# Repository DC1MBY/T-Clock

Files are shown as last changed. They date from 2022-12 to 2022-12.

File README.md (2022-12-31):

# T-Clock: A Nixie tube clock build from transistors only

The first working transistor demo just had its 75th anniversary: https://en.wikipedia.org/wiki/History_of_the_transistor How to better celebrate it than having (103 times) fun with transistors? Some time back I discovered in the German magazine Funkschau 1969 #2, #3 and #10 the article "Digital-Uhr zum Selbstbau", a copy of it can be found here: http://www.nixieuhren.de/downloads/digitaluhrfunkschau.pdf 
It is a Nixie clock design completely based on transistors. I always wanted to build one of these. When I found out that Kicad supports auto routing (freeRouting/LayoutEditor), that became much more feasible. This repository contains the PCB designs as well as OpenScad designs for the case and the spacer for the Nixies.

**Warning: Nixie tubes require high voltages which can be lethal. Please be careful!**

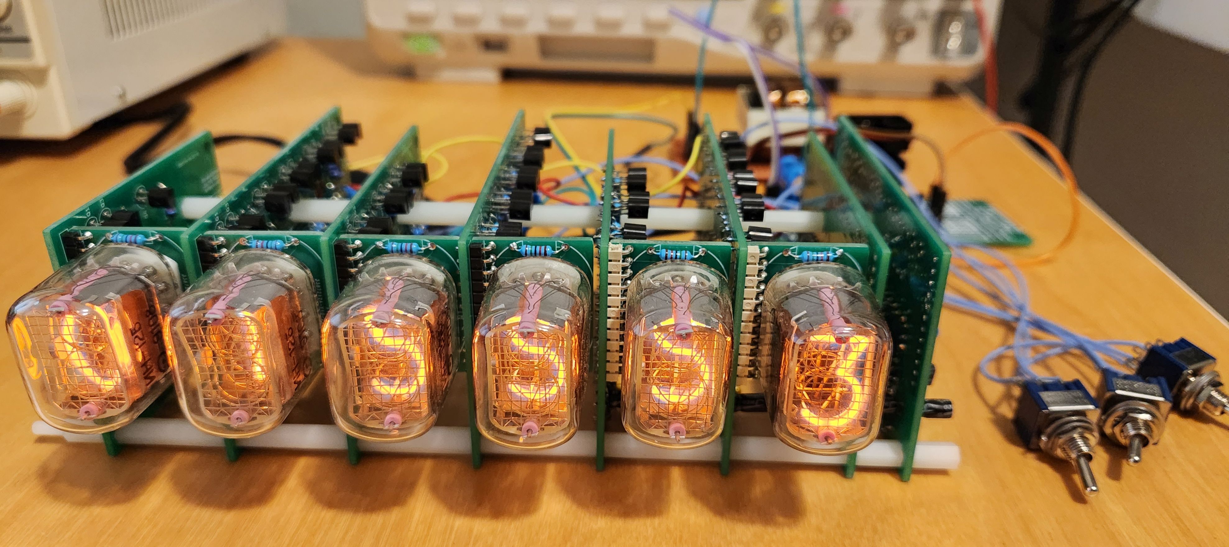
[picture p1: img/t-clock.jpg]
t-clock


## Changes compared to the original

### Prescaler

I'm living in US, so I had to modify the prescaler from 50Hz to 60Hz mains frequency. /60 can be very easy implemented as /10 followed by /6. This allowed to re-use the PCBs of the first and second digit, just the decoding/high voltage transistors aren't populated on these PCBs. Luckily the usual PCB prototype manufactures always send a couple of copies of each ordered PCB, very handy for that.

### Schmitt-Trigger

The Schmitt trigger for converting the sinusoidal mains signal to a square wave feeding the prescaler was converted from Ge to Si. Because the circuit is small, I didn't develop a pcb for it but implemented it on a piece of perfboard. 

### Power Supply

Power source is a 12VAC 1.5A wall wart, this way no routing of mains voltage is needed. The high voltage for the Nixie tubes is generated by a small reverse operated transformer. Because of the high DC resistance of the transformer the supply is very soft and reaching the correct voltage (about 170V) is a bit critical. Therefore the rectified 12V was added in order to reach the required voltage. If this is needed or not will depend on the type of transformer. The Ge transistors of the 12V regulator were replaced by Si ones. The pass transistor needs a heatsink. A perfboard was used for the power supply. 

## Obtaining the parts

All components are easily obtainable except for the Nixie tubes. The IN-12 Nixie tube can still be found on ebay. Because the decimal point isn't used, both the IN-12A and IN-12B version will work fine.

## Block Diagram

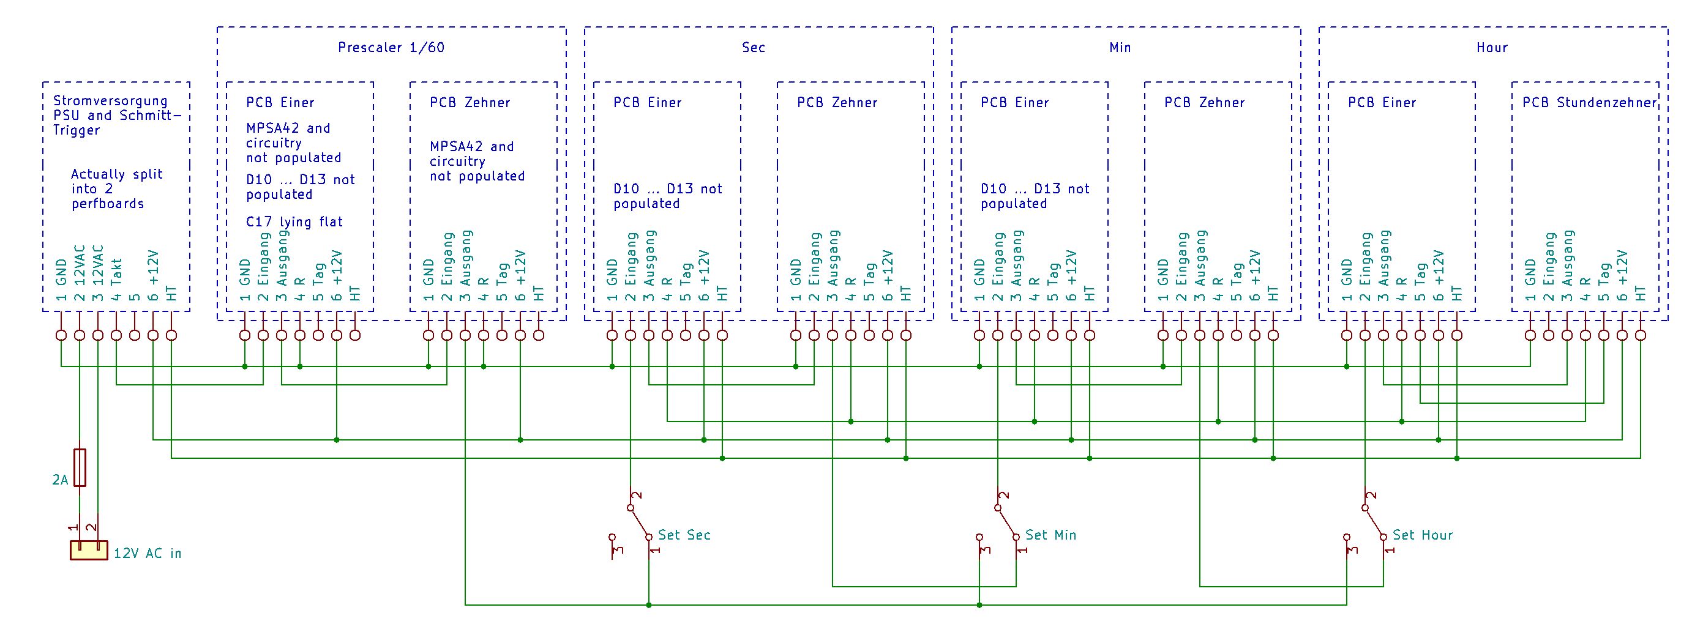
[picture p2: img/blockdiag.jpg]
Block Diagram


## Mechanical

### Boards

The boards are stacked with 25mm M3 spacers and 10mm M3 spacers. The stack will be mounted to the case.
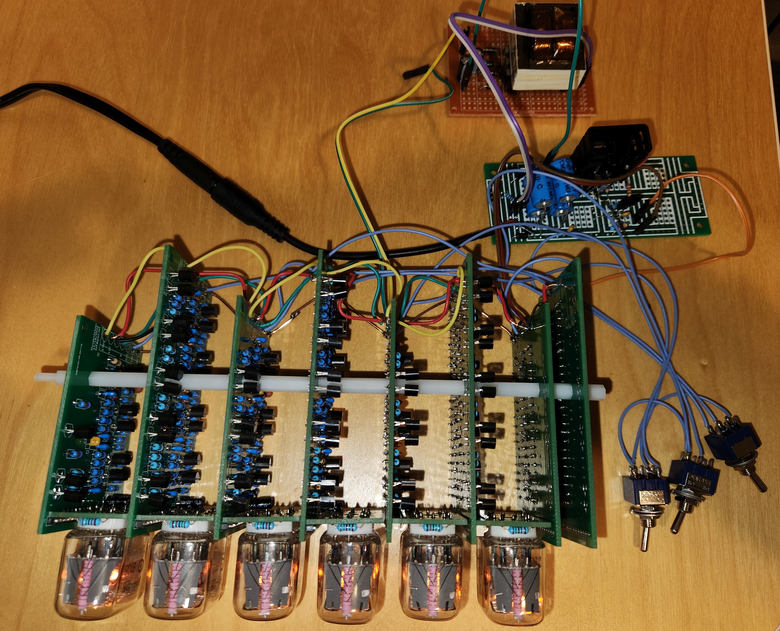
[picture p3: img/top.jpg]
boards


### Nixie

Even more difficult to source than the Nixie tubes themselves are sockets for them. Therefore I soldered the Nixie tubes directly to the PCB. I've seen this method first in Russian test equipment offered on a flea market. For equally spacing the Nixie from the PCB a 3d printed spacer is used (in12b.scad).  
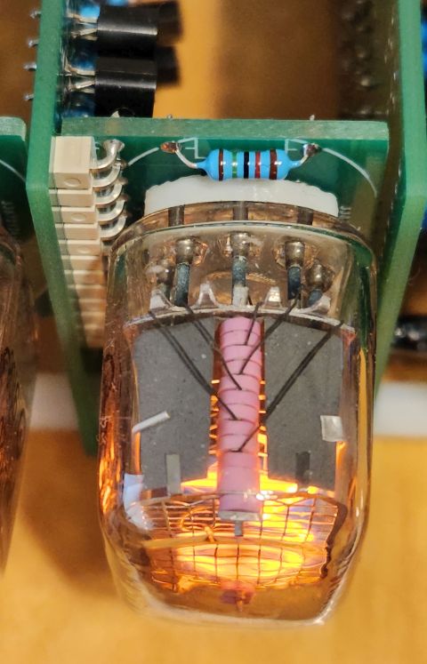
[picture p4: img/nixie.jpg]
nixie


### Case

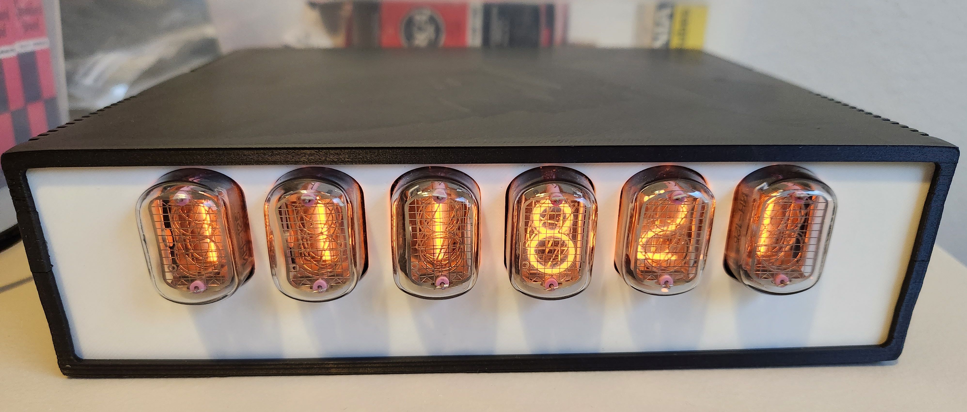
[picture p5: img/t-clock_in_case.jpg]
t-clock in case


The case is based on the fantastic Ultimate Box Maker https://github.com/jbebel/Ultimate-Box-Maker. The pcb mounts and the tabs are using M2.5 metal threaded inserts https://www.amazon.com/gp/product/B07NBPGTY2 .

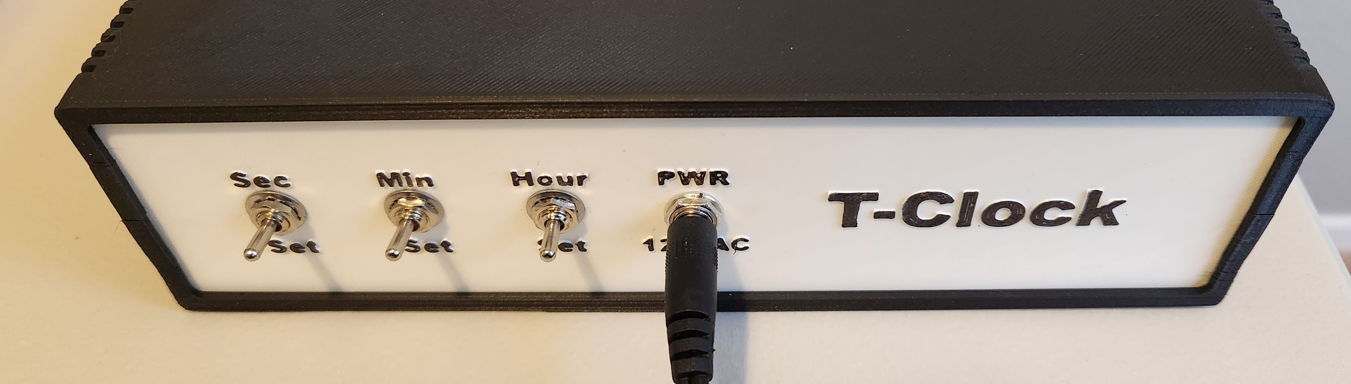
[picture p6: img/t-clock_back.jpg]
t-clock back


The letters in the back panel are painted black with a sharpie. 

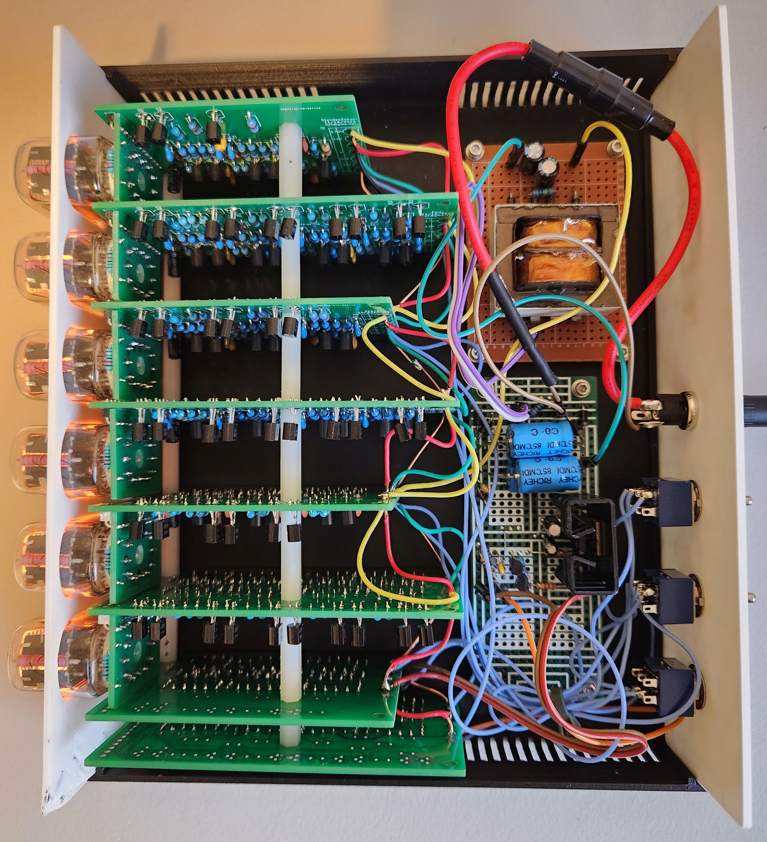
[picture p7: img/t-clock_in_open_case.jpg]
t-clock in open case


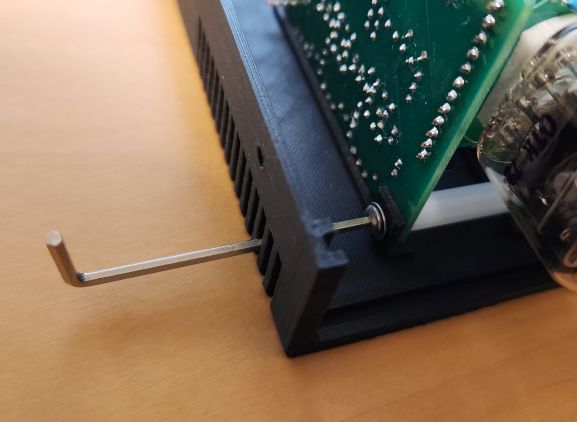
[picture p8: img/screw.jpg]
screw mounting the stack to the case


The screws can be installed with an Allen key through the vent. For the picture I didn't have the front panel installed yet, but the front panel needs to be installed before the screws. In this version of the case the tab was 2 mm thick and I broke one off. Therefore I made it 4mm thick. It might be best to print it with 100% infill for added stability.

## Summary

Things I might change if I'd redesign it:
- Move the Nixies to the center of the pcb for better looks
- Add a second mounting hole to the pcbs on the lower side (I made the usual mistake to first layout the pcbs and then think about the case)
- Change to SMD components. I forgot how tedious it is to bend the leads and clip them.   

That was a fun project. It turned out to be quite easy to build a more than 50 years old design today. I fear one of today's "modern" Nixie clock designs based on an microcontroller will be much harder to build in 50 years from now, the toolchain for the controller will not work with Windows 2070, USB20 will be incompatible with USB2.0, ... ;)

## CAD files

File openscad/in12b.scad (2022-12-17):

//
//
// IN12 spacer
//
//

pinradius = 1.8 / 2;

difference(){
    cylinder(h = 3.5,r = 22/2, center = true, $fn=360);
    
    union(){
    translate([0,0,-5])
    cylinder(h = 100,r = 3.5, $fn=360);

    translate([0,-9,-5])
    cylinder(h = 100,r = pinradius, $fn=360);
    
    translate([0,9,-5])
    cylinder(h = 100,r = pinradius, $fn=360);
    
    translate([4,-8,-5])
    cylinder(h = 100,r = pinradius, $fn=360);
    
    translate([4,8,-5])
    cylinder(h = 100,r = pinradius, $fn=360);
    
    translate([-4,-8,-5])
    cylinder(h = 100,r = pinradius, $fn=360);
    
    translate([-4,8,-5])
    cylinder(h = 100,r = pinradius, $fn=360);
    
    translate([11.5/2,4.5,-5])
    cylinder(h = 100,r = pinradius, $fn=360);
    
    translate([11.5/2,-4.5,-5])
    cylinder(h = 100,r = pinradius, $fn=360);

    translate([-11.5/2,4.5,-5])
    cylinder(h = 100,r = pinradius, $fn=360);
    
    translate([-11.5/2,-4.5,-5])
    cylinder(h = 100,r = pinradius, $fn=360);

    translate([11.5/2,0,-5])
    cylinder(h = 100,r = pinradius, $fn=360);
    
    translate([11.5/2,0,-5])
    cylinder(h = 100,r = pinradius, $fn=360);

    translate([-11.5/2,0,-5])
    cylinder(h = 100,r = pinradius, $fn=360);
    
    translate([-11.5/2,0,-5])
    cylinder(h = 100,r = pinradius, $fn=360);

    translate([7.5,-11,-5])
    cube([22,22,20]);

    translate([-22-7.5,-11,-5])
    cube([22,22,20]);


    }
}

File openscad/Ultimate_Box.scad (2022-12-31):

/* Box design originally by:
////////////////////////////////////////////////////////////////////
              -    FB Aka Heartman/Hearty 2016     -
              -   http://heartygfx.blogspot.com    -
              -       OpenScad Parametric Box      -
              -         CC BY-NC 3.0 License       -
////////////////////////////////////////////////////////////////////

Improved by jbebel:
http://github.com/jbebel/Ultimate-Box-Maker

To create a box, start by modifying the numerical parameters in the sections
below. This can be accomplished using a release of OpenSCAD newer than 2015.03.
As of the time of writing, this means that a development snapshot is required.
The Thingiverse Customizer may also potentially work, but at the time of
writing, it was inoperable.

The simplest choice is to hand-edit the .scad file. Feature toggles are
annotated with a comment. The other numerical parameters are measurements in
mm. Everything is parametrized, so if you double all the non-feature parameters
you will double the box size in every dimension. Certain parameters are derived
from other parameters. If you wish to override them, you may, but sensible
defaults have been chosen. Notably the design in this revision is particularly
PCB-centric, in that you should start with your PCB size and adjust the margins
around it to determine the box size. If you care more about the box size, you
can set the Length, Width, and Height explicitly, but read the comments around
them.

Once your box is sized appropriately, you can use the Panel modules to design
the holes and text for the front and back panels. Helper variables are provided
to assist you in positioning these holes relative to the PCB, if your holes are
for PCB-mounted components.

When you are ready to print, adjust the values in the "STL element to export"
section, and export each part one at a time.

Experimental options are provided for a screwless design, but these are
untested. In particular, the box fixation tabs may need thicknesses adjusted
in order to have the appropriate flexibility.
*/

// preview[view:north east, tilt:top diagonal]
//----------------------- Box parameters ---------------------------

/* [Box options] */
// - Wall thickness
Thick = 2;
// - Panel thickness
PanelThick = 2;
// - Font Thickness
FontThick = 0.5;
// - Filet Radius
Filet = 2;
// - 0 for beveled, 1 for rounded
Round = 1; // [0:No, 1:Yes]
// - Printer margin around interior cutouts
CutoutMargin = 0.3;
// - Margin between mating parts
PartMargin = 0.1;
// - PCB feet? (x4)
PCBFeet = 1; // [0:No, 1:Yes]
// - Decorations?
Decorations = 1; // [0:No, 1:Yes]
// - Decorations to ventilation holes
Vent = 1; // [0:No, 1:Yes]
// - Decoration-Holes width (in mm)
Vent_width = 2;
// - Tolerance (Panel/rails gap on one edge)
PanelThickGap = CutoutMargin + PartMargin;
PanelVerticalGap = PartMargin;
PanelHorizontalGap = CutoutMargin + PartMargin;


/* [Box Fixation Tabs] */
// - Side screw hole (or snap) diameter
ScrewHole = 3.7;  // M2.5 metal threaded insert
// - Screw thread major diameter for outer shell
BoxHole = 2.8448;
// Thickness of fixation tabs
TabThick = 5.5;
// Back left tab
BLTab = 1; // [0:Bottom, 1:Top]
// Back right tab
BRTab = 1; // [0:Bottom, 1:Top]
// Front left tab
FLTab = 1; // [0:Bottom, 1:Top]
// Front right tab
FRTab = 1; // [0:Bottom, 1:Top]
// EXPERIMENTAL: Snap tabs
SnapTabs = 0; // [0:Screws, 1:Snaps]


/* [PCB options] */
// - PCB Length
PCBLength = 40;
PCBLength_2 = 50;
// - PCB Width
PCBWidth = 100;
PCBWidth_2 = 70;
// Offset of the 2nd pcb to the 1st
PCB2XOff = -10;
PCB2YOff = -75;
// - PCB Thickness
PCBThick = 1.6;
// You likely need to maintain |TabThick| margin on the left and right for tabs
// and whatnot.
// - Margin between front panel and PCB
FrontEdgeMargin = 110;
// - Margin between back panel and PCB
BackEdgeMargin = 20;
// - Margin between left wall and PCB
LeftEdgeMargin = 84.8+8;
// - Margin between right wall and PCB
RightEdgeMargin = 8+8;
// - Margin between top of PCB and box top.
TopMargin = 53.34-1.6-6;


/* [PCB_Feet] */
// - Foot height above box interior
FootHeight = 6;
// - Foot diameter
FootDia = 8;
// - Hole diameter, or peg for screwless design
FootHole = 3.7; // M2.5 metal threaded insert
// - EXPERIMENTAL Screwless design
Screwless = 0; // [0:Screws, 1:Screwless]
FootFilet = FootHeight/4;

// Foot centers are specified as distance from PCB back-left corner.
// X is along the "length" axis, and Y is along the "width" axis.
// - Foot 1 distance from back PCB edge
Foot1X = 5;
// - Foot 1 distance from left PCB edge
Foot1Y = 4;
// - Foot 2 distance from back PCB edge
Foot2X = 5;
// - Foot 2 distance from right PCB edge
Foot2YFromEdge = 4;
Foot2Y = PCBWidth - Foot2YFromEdge;
// - Foot 3 distance from front PCB edge
Foot3XFromEdge = 5;
Foot3X = PCBLength - Foot3XFromEdge;
// - Foot 3 distance from left PCB edge
Foot3Y = 4;
// - Foot 4 distance from front PCB edge
Foot4XFromEdge = 5;
Foot4X = PCBLength - Foot4XFromEdge;
// - Foot 4 distance from right PCB edge
Foot4YFromEdge = 4;
Foot4Y = PCBWidth - Foot4YFromEdge;

// 2nd PCB
// Foot centers are specified as distance from PCB back-left corner.
// X is along the "length" axis, and Y is along the "width" axis.
// - Foot 1 distance from back PCB edge
Foot1X_2 = 2.5;
// - Foot 1 distance from left PCB edge
Foot1Y_2 = 2.5;
// - Foot 2 distance from back PCB edge
Foot2X_2 = 2.5;
// - Foot 2 distance from right PCB edge
Foot2YFromEdge_2 = 2.5;
Foot2Y_2 = PCBWidth_2 - Foot2YFromEdge_2;
// - Foot 3 distance from front PCB edge
Foot3XFromEdge_2 = 2.5;
Foot3X_2 = PCBLength_2 - Foot3XFromEdge_2;
// - Foot 3 distance from left PCB edge
Foot3Y_2 = 2.5;
// - Foot 4 distance from front PCB edge
Foot4XFromEdge_2 = 2.5;
Foot4X_2 = PCBLength_2 - Foot4XFromEdge_2;
// - Foot 4 distance from right PCB edge
Foot4YFromEdge_2 = 2.5;
Foot4Y_2 = PCBWidth_2 - Foot4YFromEdge_2;


/* [STL element to export] */
// - Top shell
TShell = 0; // [0:No, 1:Yes]
// - Bottom shell
BShell = 1; // [0:No, 1:Yes]
// - Front panel
FPanL = 0; // [0:No, 1:Yes]
// - Back panel
BPanL = 0; // [0:No, 1:Yes]
// - Panel holes and text
PanelFeatures = 1; // [0:No, 1:Yes]


/* [Hidden] */
// - Shell color
Couleur1 = "Orange";
// - Panel color
Couleur2 = "OrangeRed";
// - Text color
TextColor = "White";
// - making decorations thicker if it is a vent to make sure they go through
// shell
// Add a small number to Thick in case Filet is 0.
Dec_Thick = Vent ? Thick*1.001 + Filet : Thick/2;
// Separate vents with a square pillar by default.
Dec_Spacing = Thick + Vent_width;
// X offset to center of first vent
Dec_Offset = Thick*2 + PanelThick + PanelThickGap*2 + Dec_Spacing - Vent_width/2;

// Resolution based on Round parameter. Set this first number to something
// smaller to speed up processing. It should always be a multiple of 4.
Resolution = Round ? 100: 4;

/* Calculate box dimensions from PCB. If you want a more box-centric design
   where the outer diameter of the box matters more than the margins around
   the PCB you can set these manually. The PCB will still be placedaccording
   to the left and back margins, and if you want to use the screwless box
   design, you will need to set the TopMargin to
   (Height - Thick*2 - FootHeight - PCBThick)
*/
Length = PCBLength + FrontEdgeMargin + BackEdgeMargin + ((Thick + PanelThick + PanelThickGap*2)*2);
Width = PCBWidth + LeftEdgeMargin + RightEdgeMargin + Thick*2;
Height = FootHeight + PCBThick + TopMargin + Thick*2;
echo("Box: ", Length=Length, Width=Width, Height=Height);
// X position inset of mounting holes and tabs
MountInset = Thick*3 + PanelThick + PanelThickGap*2 + ScrewHole*4;

// Calculate panel dimensions from box dimensions.
PanelWidth = Width - Thick*2 - PanelHorizontalGap*2;
PanelHeight = Height - Thick*2 - PanelVerticalGap*2;


/*  Panel Manager

    Use the below 4 modules to produce holes and text on the front and back
    panels. The holes modules should contain instances of SquareHole or
    CylinderHole defined later in this file. The text modules should contain
    instances of LText or CText defined later in this file. It is
    recommended to use variables that you define for your needs to create
    the size and positions of these objects.
*/

// Calculate board-relative positions with respect to the panel, for
// convenience in placing panel elements.
TopOfBoardWRTPanel = FootHeight + PCBThick - PanelVerticalGap;
LeftEdgeOfBoardWRTFPanel = LeftEdgeMargin - PanelHorizontalGap;
LeftEdgeOfBoardWRTBPanel = RightEdgeMargin - PanelHorizontalGap;
// Visible panel edges
PanelBottomEdge = Thick - PanelVerticalGap;
PanelTopEdge = PanelHeight - Thick + PanelVerticalGap;
PanelLeftEdge = Thick - PanelHorizontalGap;
PanelRightEdge = PanelWidth - Thick + PanelHorizontalGap;


// Holes for front panel
module FPanelHoles() {
    // SquareHole(On/Off, Xpos,Ypos,Length,Width,Filet)
    // CylinderHole(On/Off, Xpos, Ypos, Diameter)
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

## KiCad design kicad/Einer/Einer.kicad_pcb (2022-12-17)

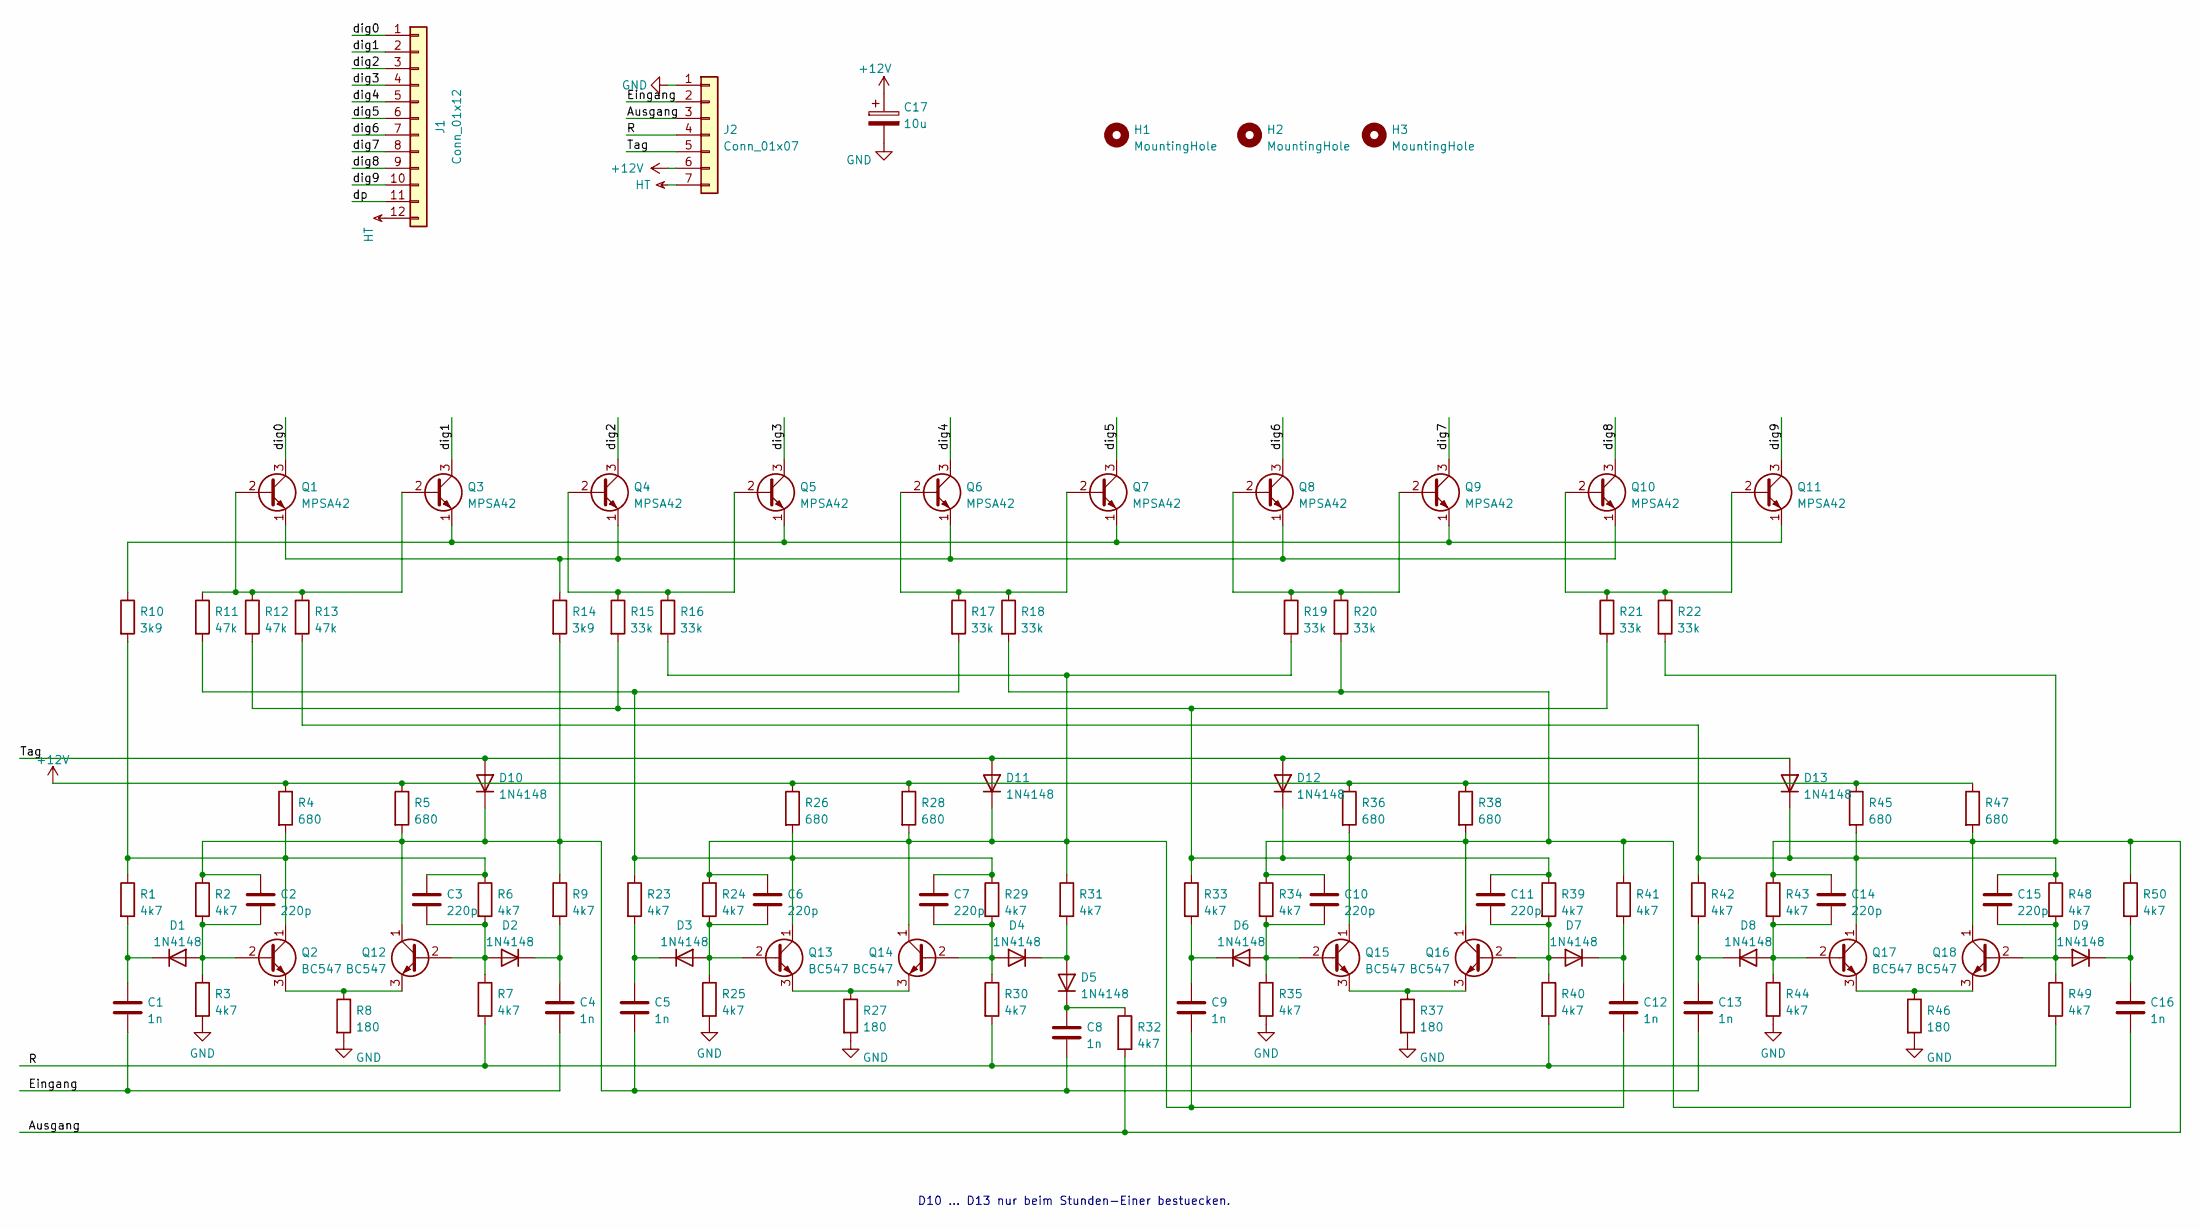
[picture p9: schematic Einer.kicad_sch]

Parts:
C1, C4, C5, C8, C9, C12, C13, C16: 1n; C_Disc_D5.0mm_W2.5mm_P2.50mm
C2, C3, C6, C7, C10, C11, C14, C15: 220p; C_Disc_D5.0mm_W2.5mm_P2.50mm
C17: 10u; CP_Radial_D5.0mm_P2.50mm
D1, D2, D3, D4, D5, D6, D7, D8, D9, D10, D11, D12, D13: 1N4148; D_DO-35_SOD27_P7.62mm_Horizontal
H1, H2, H3: MountingHole; MountingHole_3.2mm_M3
J1: Conn_01x12; PinHeader_1x12_P2.54mm_Vertical
J2: Conn_01x07; TerminalBlock_Phoenix_MKDS-3-7-5.08_1x07_P5.08mm_Horizontal
Q1, Q3, Q4, Q5, Q6, Q7, Q8, Q9, Q10, Q11: MPSA42; TO-92_HandSolder
Q2, Q12, Q13, Q14, Q15, Q16, Q17, Q18: BC547; TO-92_HandSolder
R1, R2, R3, R6, R7, R9, R23, R24, R25, R29, R30, R31, R32, R33, R34, R35, R39, R40, R41, R42, R43, R44, R48, R49, R50: 4k7; R_Axial_DIN0207_L6.3mm_D2.5mm_P10.16mm_Horizontal
R4, R5, R26, R28, R36, R38, R45, R47: 680; R_Axial_DIN0207_L6.3mm_D2.5mm_P10.16mm_Horizontal
R8, R27, R37, R46: 180; R_Axial_DIN0207_L6.3mm_D2.5mm_P10.16mm_Horizontal
R10, R14: 3k9; R_Axial_DIN0207_L6.3mm_D2.5mm_P10.16mm_Horizontal
R11, R12, R13: 47k; R_Axial_DIN0207_L6.3mm_D2.5mm_P10.16mm_Horizontal
R15, R16, R17, R18, R19, R20, R21, R22: 33k; R_Axial_DIN0207_L6.3mm_D2.5mm_P10.16mm_Horizontal

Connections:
+12V: C17.1, J2.6, R4.1, R5.1, R26.1, R28.1, R36.1, R38.1, R45.1, R47.1
/Ausgang: C14.1, J2.3, Q18.1 (C), R22.2, R32.2, R43.1, R47.2, R50.1
/Eingang: C1.2, C4.2, J2.2
/R: J2.4, R7.2, R30.2, R40.2, R49.2
/Tag: D10.2 (A), D11.2 (A), D12.2 (A), D13.2 (A), J2.5
/dig0: J1.1, Q1.3 (C)
/dig1: J1.2, Q3.3 (C)
/dig2: J1.3, Q4.3 (C)
/dig3: J1.4, Q5.3 (C)
/dig4: J1.5, Q6.3 (C)
/dig5: J1.6, Q7.3 (C)
/dig6: J1.7, Q8.3 (C)
/dig7: J1.8, Q9.3 (C)
/dig8: J1.9, Q10.3 (C)
/dig9: J1.10, Q11.3 (C)
/dp: J1.11
GND: C17.2, J2.1, R3.2, R8.2, R25.2, R27.2, R35.2, R37.2, R44.2, R46.2
HT: J1.12, J2.7
unnamed: C1.1, D1.1 (K), R1.2
unnamed: C2.2, D1.2 (A), Q2.2 (B), R2.2, R3.1
unnamed: C3.1, Q2.1 (C), R1.1, R4.2, R6.1, R10.2
unnamed: C3.2, D2.2 (A), Q12.2 (B), R6.2, R7.1
unnamed: C4.1, D2.1 (K), R9.2
unnamed: C5.1, D3.1 (K), R23.2
unnamed: C6.2, D3.2 (A), Q13.2 (B), R24.2, R25.1
unnamed: C7.1, Q13.1 (C), R11.2, R17.2, R23.1, R26.2, R29.1
unnamed: C7.2, D4.2 (A), Q14.2 (B), R29.2, R30.1
unnamed: C8.1, D5.1 (K), R32.1
unnamed: C9.1, D6.1 (K), R33.2
unnamed: C10.1, C16.2, Q16.1 (C), R18.2, R20.2, R34.1, R38.2, R41.1
unnamed: C10.2, D6.2 (A), Q15.2 (B), R34.2, R35.1
unnamed: C11.1, D12.1 (K), Q15.1 (C), R12.2, R15.2, R21.2, R33.1, R36.2, R39.1
unnamed: C11.2, D7.2 (A), Q16.2 (B), R39.2, R40.1
unnamed: C12.1, D7.1 (K), R41.2
unnamed: C6.1, C9.2, C12.2, D11.1 (K), Q14.1 (C), R16.2, R19.2, R24.1, R28.2, R31.1
unnamed: C13.1, D8.1 (K), R42.2
unnamed: C2.1, C5.2, C8.2, C13.2, D10.1 (K), Q12.1 (C), R2.1, R5.2, R9.1, R14.2
unnamed: C14.2, D8.2 (A), Q17.2 (B), R43.2, R44.1
unnamed: C15.1, D13.1 (K), Q17.1 (C), R13.2, R42.1, R45.2, R48.1
unnamed: C15.2, D9.2 (A), Q18.2 (B), R48.2, R49.1
unnamed: C16.1, D9.1 (K), R50.2
unnamed: D4.1 (K), D5.2 (A), R31.2
unnamed: Q1.1 (E), Q4.1 (E), Q6.1 (E), Q8.1 (E), Q10.1 (E), R14.1
unnamed: Q1.2 (B), Q3.2 (B), R11.1, R12.1, R13.1
unnamed: Q4.2 (B), Q5.2 (B), R15.1, R16.1
unnamed: Q6.2 (B), Q7.2 (B), R17.1, R18.1
unnamed: Q8.2 (B), Q9.2 (B), R19.1, R20.1
unnamed: Q10.2 (B), Q11.2 (B), R21.1, R22.1
unnamed: Q3.1 (E), Q5.1 (E), Q7.1 (E), Q9.1 (E), Q11.1 (E), R10.1
unnamed: Q2.3 (E), Q12.3 (E), R8.1
unnamed: Q13.3 (E), Q14.3 (E), R27.1
unnamed: Q15.3 (E), Q16.3 (E), R37.1
unnamed: Q17.3 (E), Q18.3 (E), R46.1

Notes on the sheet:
D10 ... D13 nur beim Stunden-Einer bestuecken.

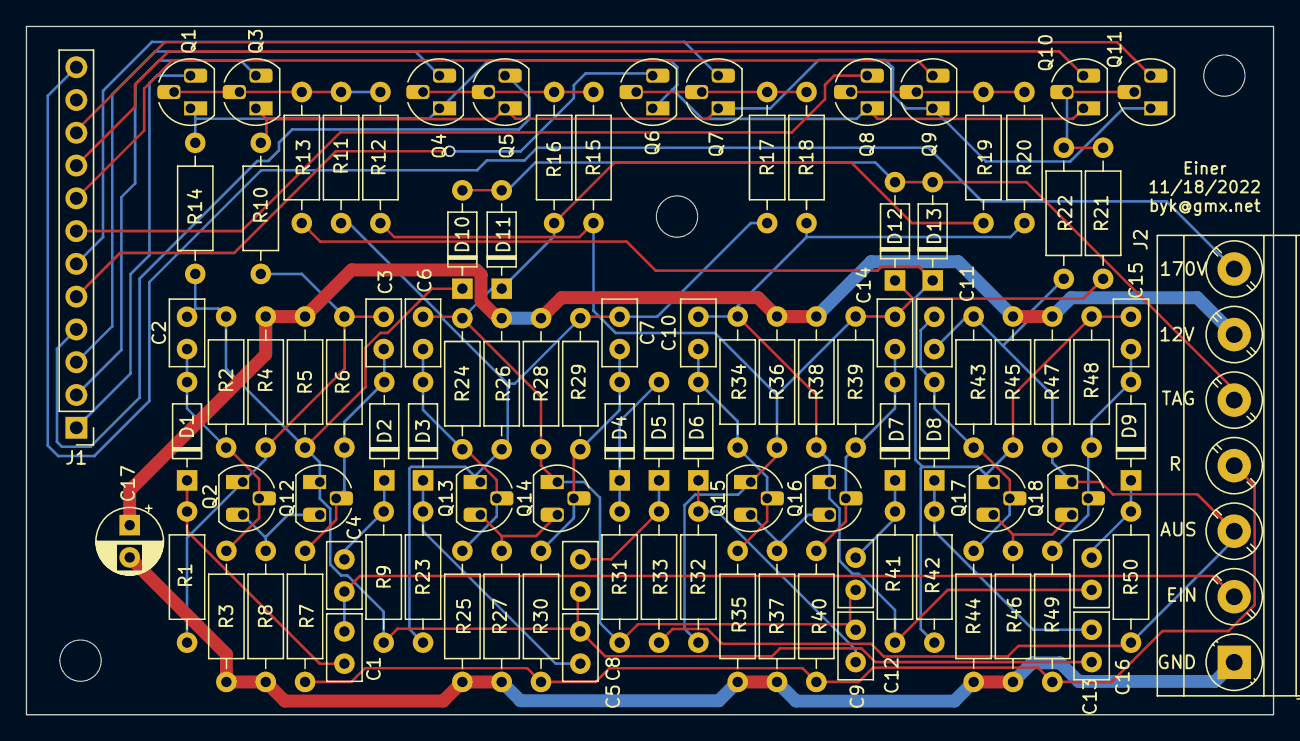
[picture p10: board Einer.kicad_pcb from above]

Board: 2 copper layers, 96.6 x 53.3 mm, 103 parts (0 on the bottom side), 52 nets.

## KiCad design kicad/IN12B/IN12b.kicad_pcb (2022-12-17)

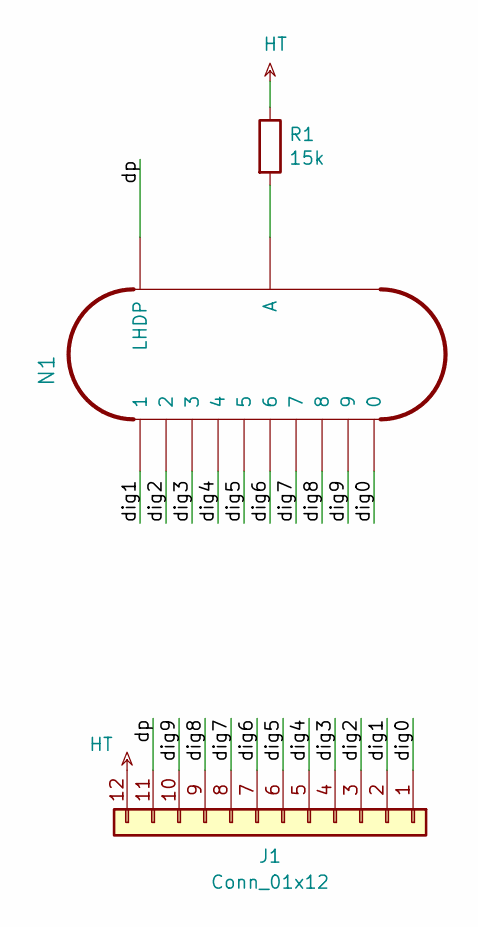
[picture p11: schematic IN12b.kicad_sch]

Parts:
J1: Conn_01x12; PinHeader_1x12_P2.54mm_Horizontal
N1: IN-12B; IN-12
R1: 15k; R_Axial_DIN0207_L6.3mm_D2.5mm_P10.16mm_Horizontal

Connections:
/dig0: J1.1, N1.0
/dig1: J1.2, N1.1
/dig2: J1.3, N1.2
/dig3: J1.4, N1.3
/dig4: J1.5, N1.4
/dig5: J1.6, N1.5
/dig6: J1.7, N1.6
/dig7: J1.8, N1.7
/dig8: J1.9, N1.8
/dig9: J1.10, N1.9
/dp: J1.11, N1.LHDP
HT: J1.12, R1.1
unnamed: N1.A, R1.2

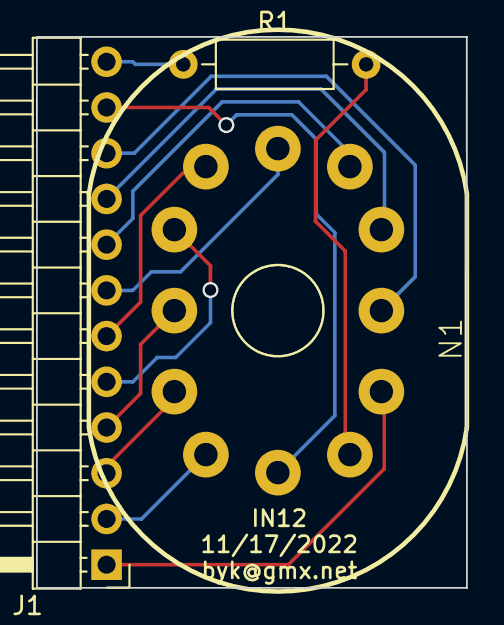
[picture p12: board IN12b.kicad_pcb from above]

Board: 2 copper layers, 23.9 x 30.6 mm, 3 parts (0 on the bottom side), 13 nets.

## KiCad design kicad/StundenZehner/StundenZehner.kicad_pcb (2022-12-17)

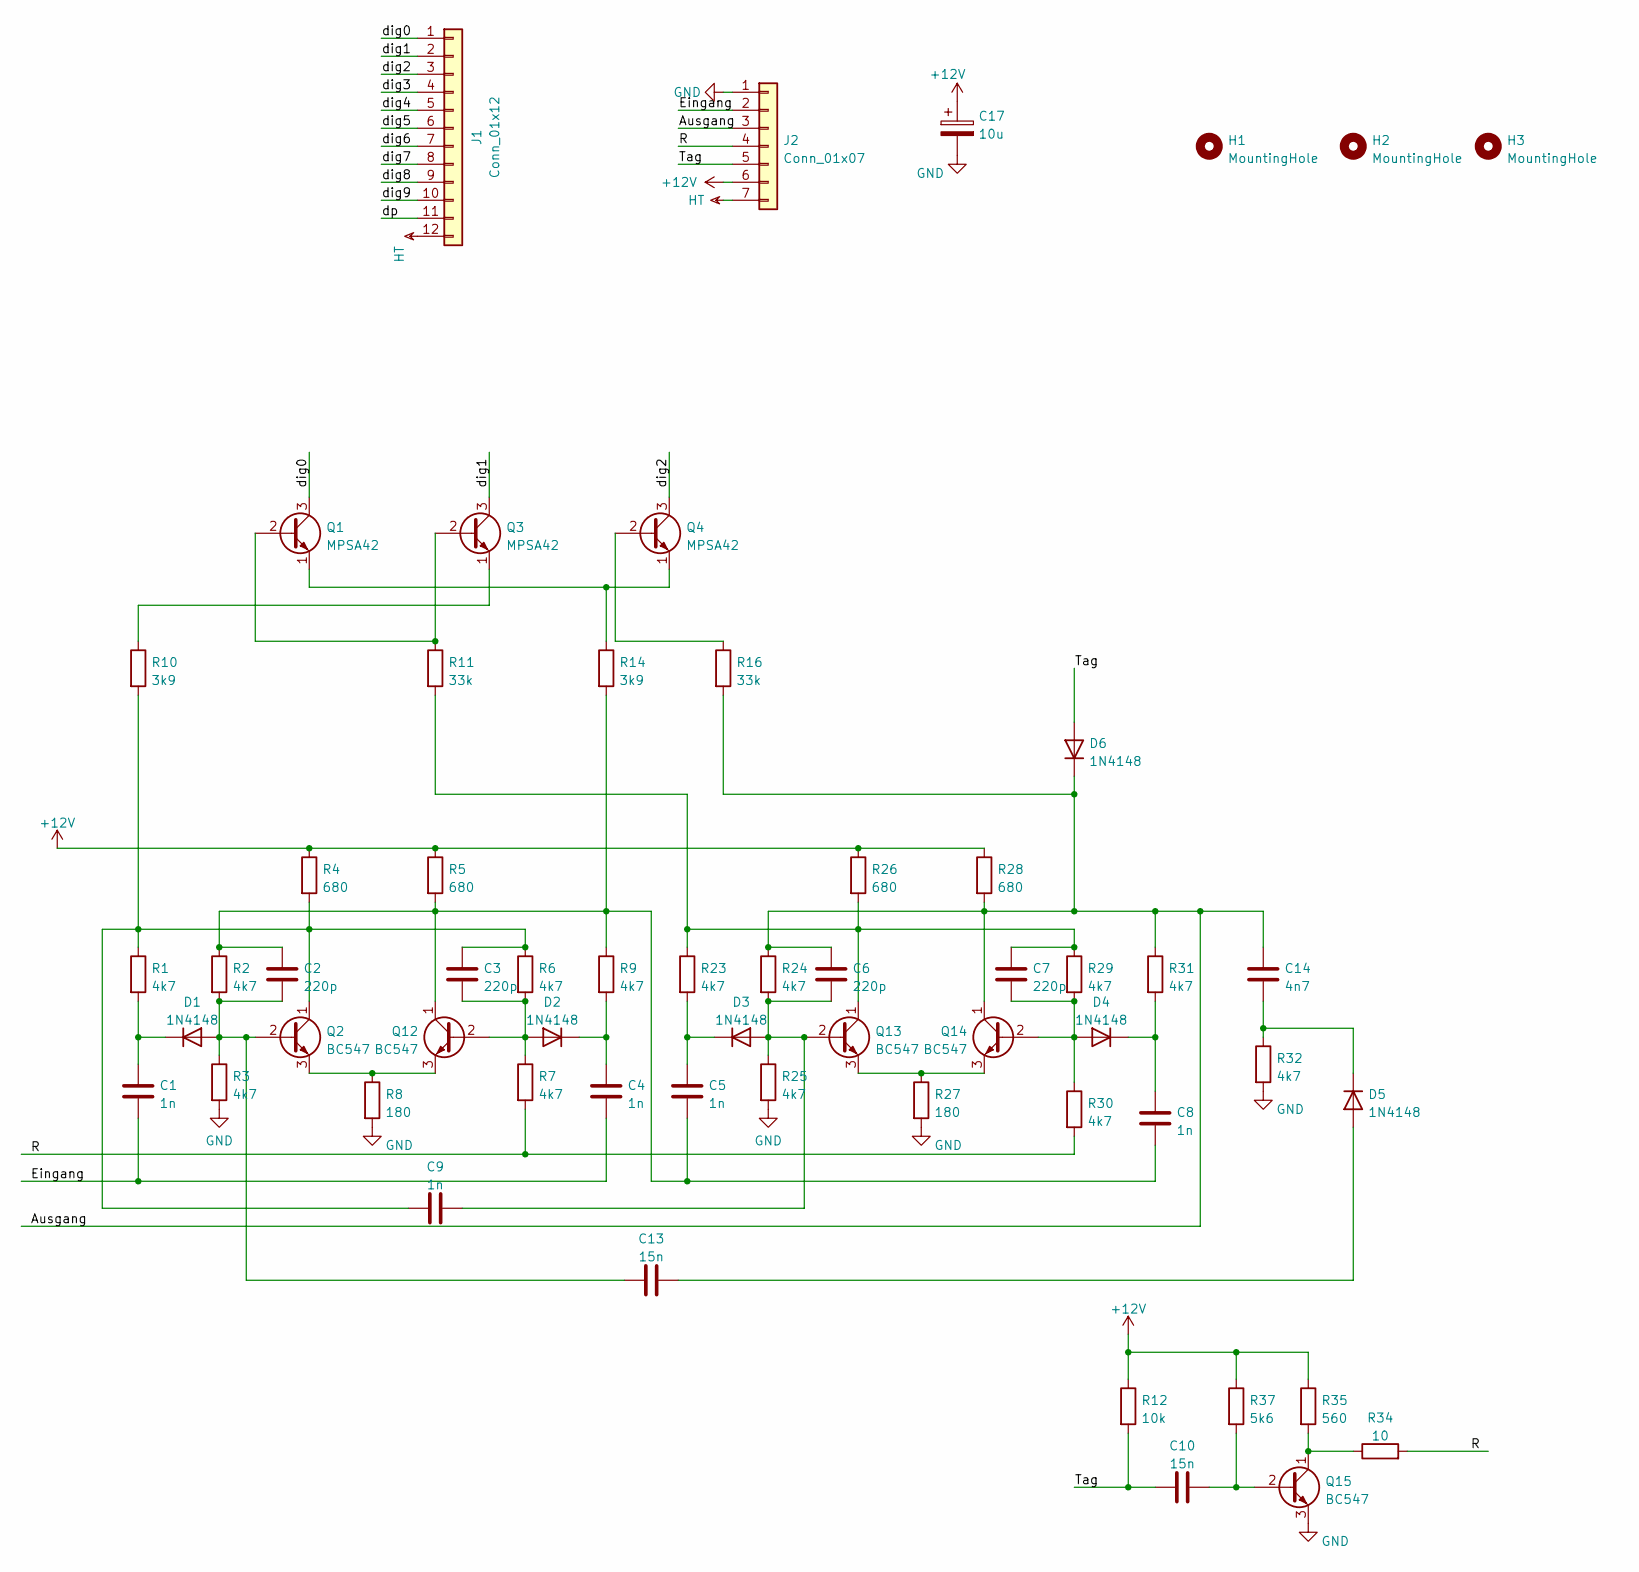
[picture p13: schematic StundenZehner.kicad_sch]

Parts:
C1, C4, C5, C8, C9: 1n; C_Disc_D5.0mm_W2.5mm_P2.50mm
C2, C3, C6, C7: 220p; C_Disc_D5.0mm_W2.5mm_P2.50mm
C10, C13: 15n; C_Disc_D5.0mm_W2.5mm_P2.50mm
C14: 4n7; C_Disc_D5.0mm_W2.5mm_P2.50mm
C17: 10u; CP_Radial_D5.0mm_P2.50mm
D1, D2, D3, D4, D5, D6: 1N4148; D_DO-35_SOD27_P7.62mm_Horizontal
H1, H2, H3: MountingHole; MountingHole_3.2mm_M3
J1: Conn_01x12; PinHeader_1x12_P2.54mm_Vertical
J2: Conn_01x07; TerminalBlock_Phoenix_MKDS-3-7-5.08_1x07_P5.08mm_Horizontal
Q1, Q3, Q4: MPSA42; TO-92_HandSolder
Q2, Q12, Q13, Q14, Q15: BC547; TO-92_HandSolder
R1, R2, R3, R6, R7, R9, R23, R24, R25, R29, R30, R31, R32: 4k7; R_Axial_DIN0207_L6.3mm_D2.5mm_P10.16mm_Horizontal
R4, R5, R26, R28: 680; R_Axial_DIN0207_L6.3mm_D2.5mm_P10.16mm_Horizontal
R8, R27: 180; R_Axial_DIN0207_L6.3mm_D2.5mm_P10.16mm_Horizontal
R10, R14: 3k9; R_Axial_DIN0207_L6.3mm_D2.5mm_P10.16mm_Horizontal
R11, R16: 33k; R_Axial_DIN0207_L6.3mm_D2.5mm_P10.16mm_Horizontal
R12: 10k; R_Axial_DIN0207_L6.3mm_D2.5mm_P10.16mm_Horizontal
R34: 10; R_Axial_DIN0207_L6.3mm_D2.5mm_P10.16mm_Horizontal
R35: 560; R_Axial_DIN0207_L6.3mm_D2.5mm_P10.16mm_Horizontal
R37: 5k6; R_Axial_DIN0207_L6.3mm_D2.5mm_P10.16mm_Horizontal

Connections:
+12V: C17.1, J2.6, R4.1, R5.1, R12.1, R26.1, R28.1, R35.1, R37.1
/Ausgang: C6.1, C14.1, D6.1 (K), J2.3, Q14.1 (C), R16.2, R24.1, R28.2, R31.1
/Eingang: C1.2, C4.2, J2.2
/R: J2.4, R7.2, R30.2, R34.2
/Tag: C10.1, D6.2 (A), J2.5, R12.2
/dig0: J1.1, Q1.3 (C)
/dig1: J1.2, Q3.3 (C)
/dig2: J1.3, Q4.3 (C)
/dig3: J1.4
/dig4: J1.5
/dig5: J1.6
/dig6: J1.7
/dig7: J1.8
/dig8: J1.9
/dig9: J1.10
/dp: J1.11
GND: C17.2, J2.1, Q15.3 (E), R3.2, R8.2, R25.2, R27.2, R32.2
HT: J1.12, J2.7
unnamed: C1.1, D1.1 (K), R1.2
unnamed: C2.1, C5.2, C8.2, Q12.1 (C), R2.1, R5.2, R9.1, R14.2
unnamed: C3.1, C9.1, Q2.1 (C), R1.1, R4.2, R6.1, R10.2
unnamed: C3.2, D2.2 (A), Q12.2 (B), R6.2, R7.1
unnamed: C4.1, D2.1 (K), R9.2
unnamed: C5.1, D3.1 (K), R23.2
unnamed: C6.2, C9.2, D3.2 (A), Q13.2 (B), R24.2, R25.1
unnamed: C7.1, Q13.1 (C), R11.2, R23.1, R26.2, R29.1
unnamed: C7.2, D4.2 (A), Q14.2 (B), R29.2, R30.1
unnamed: C8.1, D4.1 (K), R31.2
unnamed: C10.2, Q15.2 (B), R37.2
unnamed: C2.2, C13.1, D1.2 (A), Q2.2 (B), R2.2, R3.1
unnamed: C13.2, D5.2 (A)
unnamed: C14.2, D5.1 (K), R32.1
unnamed: Q1.1 (E), Q4.1 (E), R14.1
unnamed: Q1.2 (B), Q3.2 (B), R11.1
unnamed: Q3.1 (E), R10.1
unnamed: Q4.2 (B), R16.1
unnamed: Q2.3 (E), Q12.3 (E), R8.1
unnamed: Q13.3 (E), Q14.3 (E), R27.1
unnamed: Q15.1 (C), R34.1, R35.2

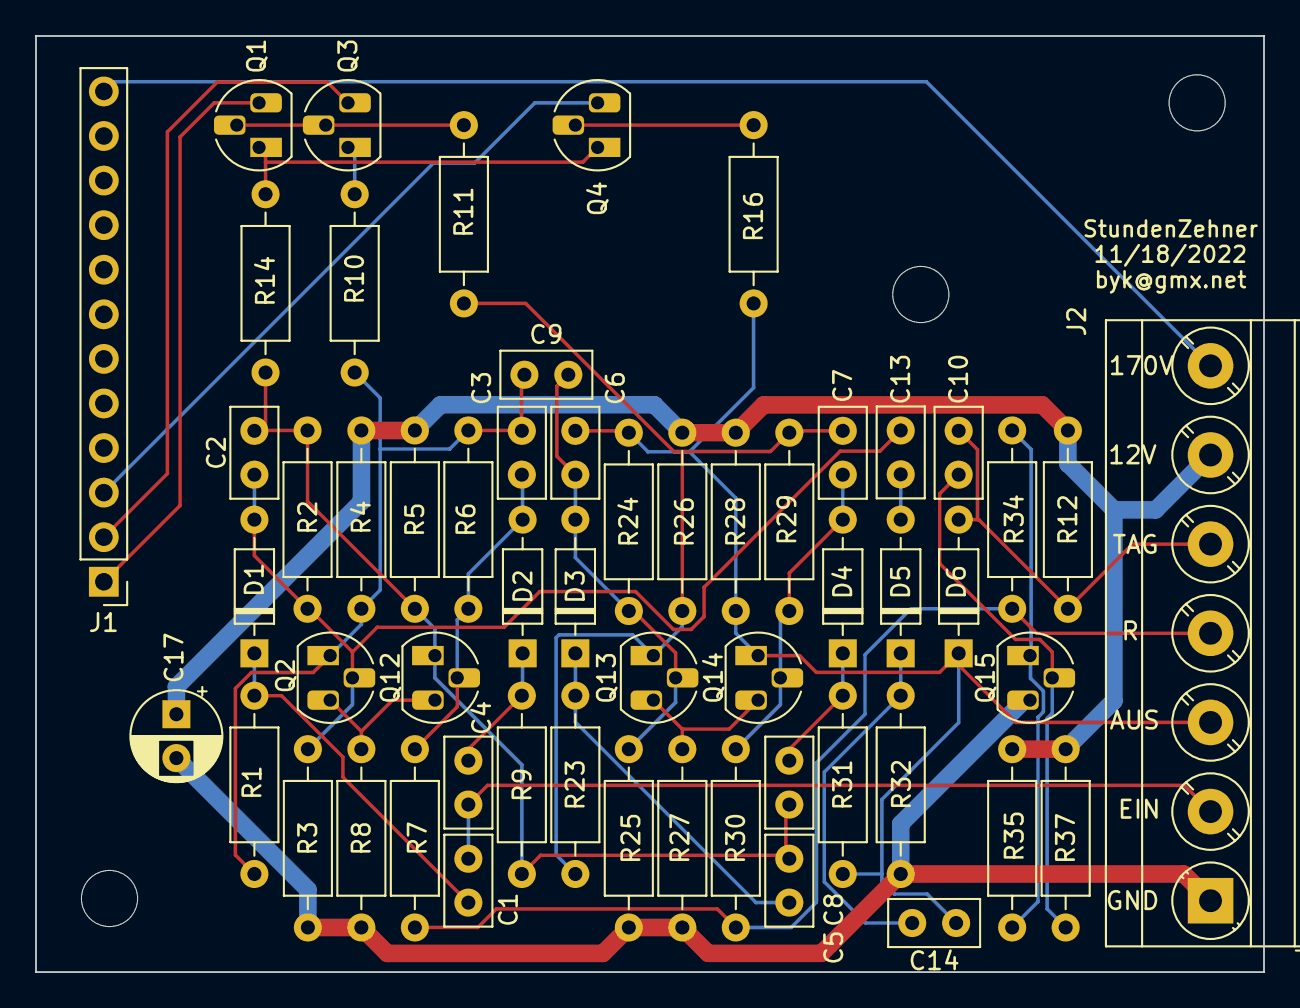
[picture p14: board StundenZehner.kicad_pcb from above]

Board: 2 copper layers, 70.0 x 53.3 mm, 59 parts (0 on the bottom side), 31 nets.

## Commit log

2022-12-17 Added Kicad and Openscad files
    [Einer.kicad_pcb, Einer.kicad_sch, IN12b.kicad_pcb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]
2022-12-31 Updated Readme, added box Openscad file
    [Ultimate_Box.scad]
2022-12-31 Added block diagram
    [blockdiag.kicad_sch]
